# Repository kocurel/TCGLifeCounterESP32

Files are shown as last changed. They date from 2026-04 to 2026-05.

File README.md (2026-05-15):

# An electronic ESP32-C3-powered life counter for Trading Card Games. 
## Made with the players of Magic the Gathering and Yu-Gi-Oh in mind.

The main goal for this project was to implement the basic LifeTap features.
I expanded on some of the features by tracking more variables 
(letting the player rename the value names as they see fit).

Anticipating players making mistakes, the device tracks change history 
letting the player undo to a selected point in time.

As an added extra, I included a dice page that lets the user simulate dice throws using esp_random().
The included dice options are (coin, d3, d4, d6, d8, d10, d12, d20, d100). It's possible to throw 1-4 dice at once and reroll any of the results.

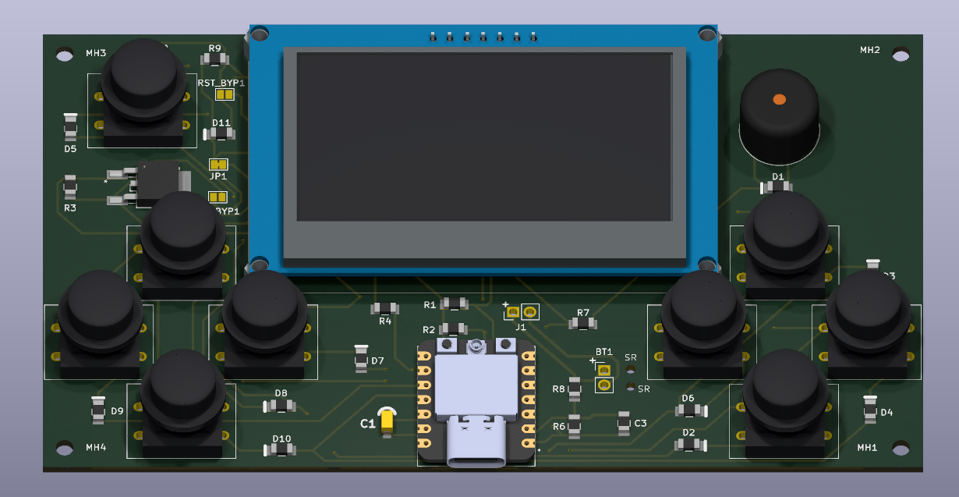
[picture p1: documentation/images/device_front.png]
3D Kicad render

A 3D render generated in Kicad

# The main interface
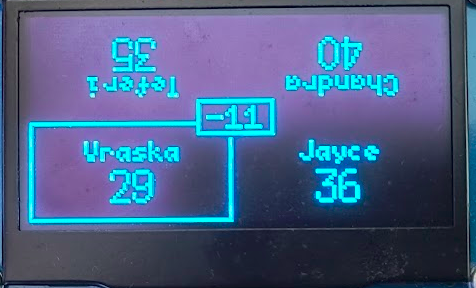
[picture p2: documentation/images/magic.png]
MtG commander gameplay
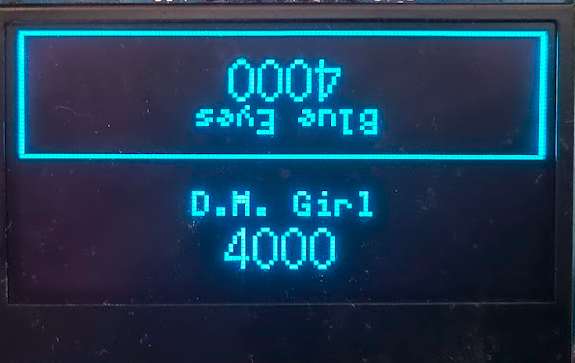
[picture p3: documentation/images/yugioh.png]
Yugioh gameplay
 

# Hardware
The main components of the device are:
1. [SEEED XIAO ESP32-C3](https://botland.store/esp32-wifi-and-bt-modules/21859-seeed-xiao-esp32-c3-wifibluetooth-seeedstudio-113991054.html)
2. [msalamon SSD1309 2.42" OLED display](https://sklep.msalamon.pl/produkt/wyswietlacz-oled-242-128x64px-niebieski/)
3. [A 3x3 12x12mm tactile switch matrix](https://www.tme.eu/pl/en/details/ts24n/microswitches-tact/knitter-switch/ts-24-n/)
4. A passive buzzer
5. 10x 1N4148 diodes
6. A 1050mAh LiPo battery

## The schematics

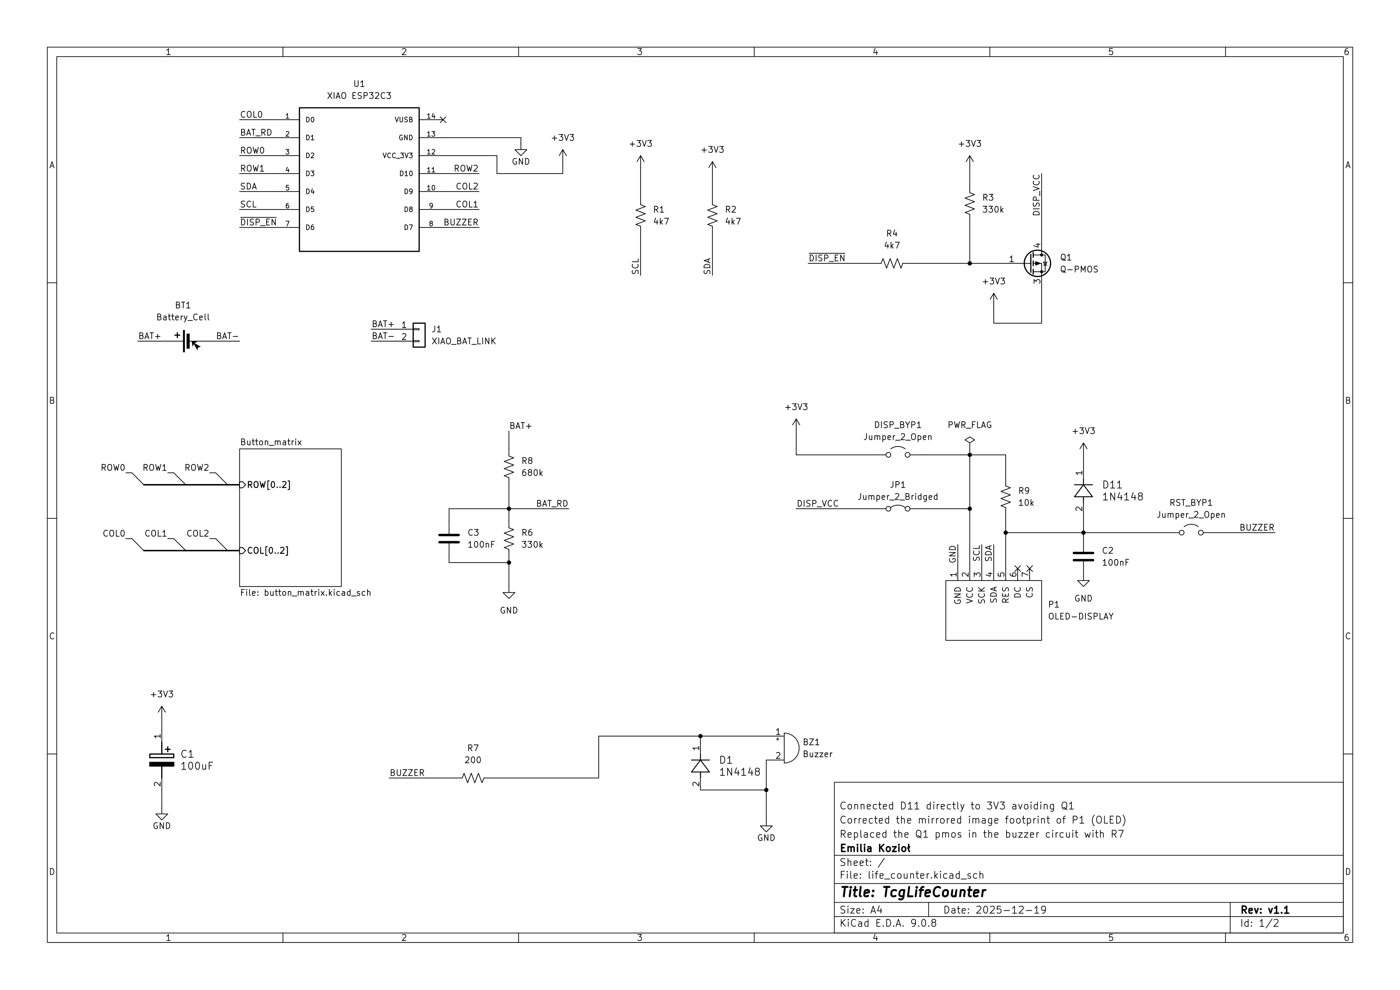
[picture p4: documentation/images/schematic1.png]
Kicad schematic page 1

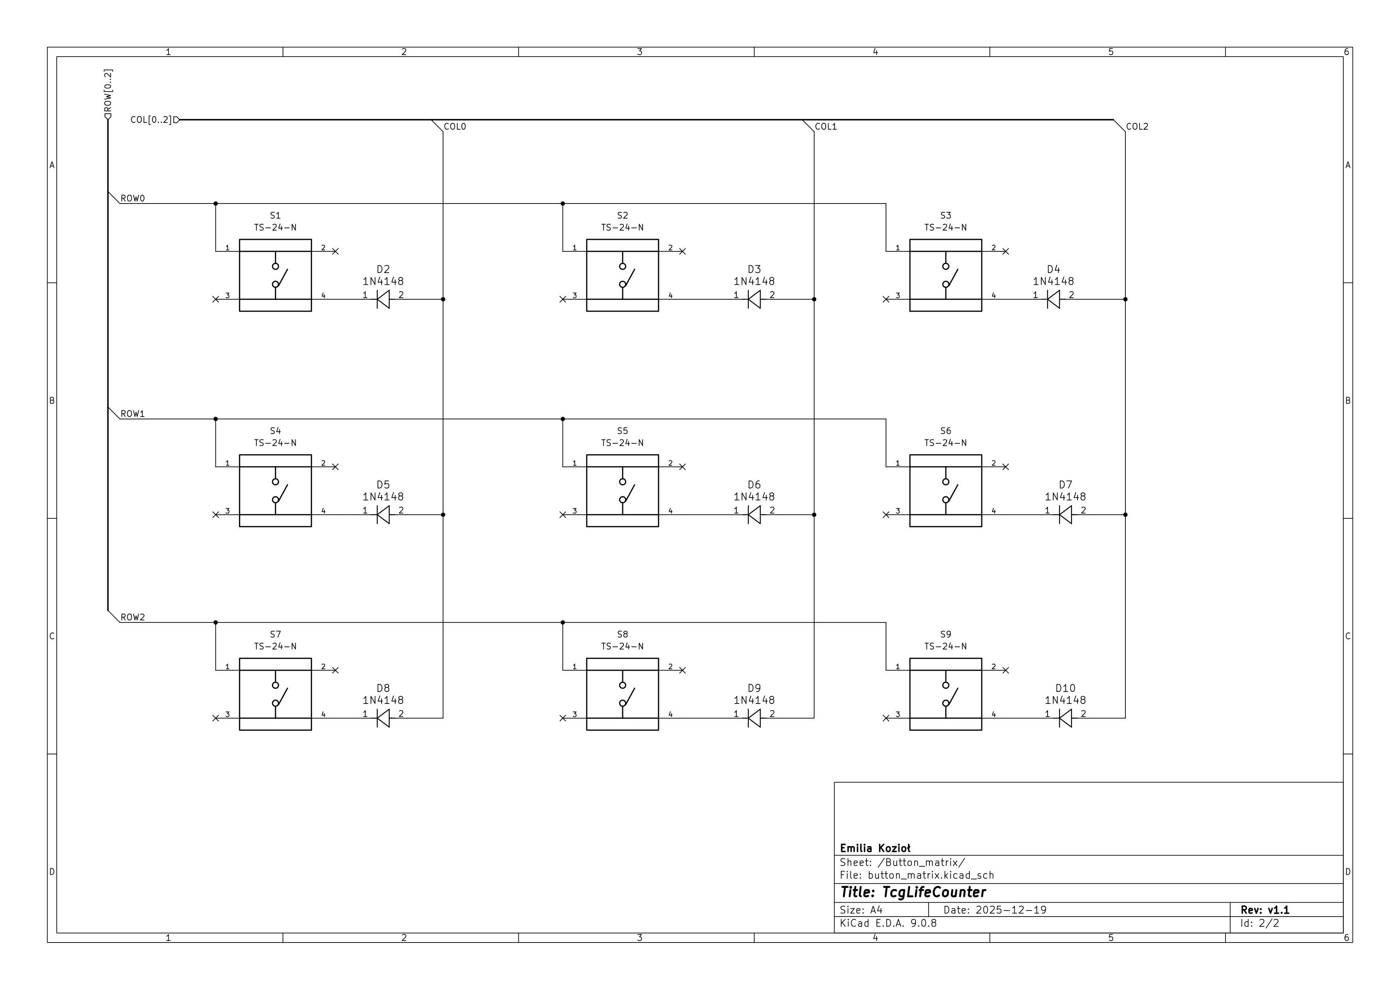
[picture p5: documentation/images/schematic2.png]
Kicad schematic page 2


# Software
When I made the project I used three main components:
1. ESP-IDF
2. [u8g2](https://github.com/olikraus/u8g2)
3. [u8g2-hal-esp-idf](https://github.com/mkfrey/u8g2-hal-esp-idf)

## GUIFramework
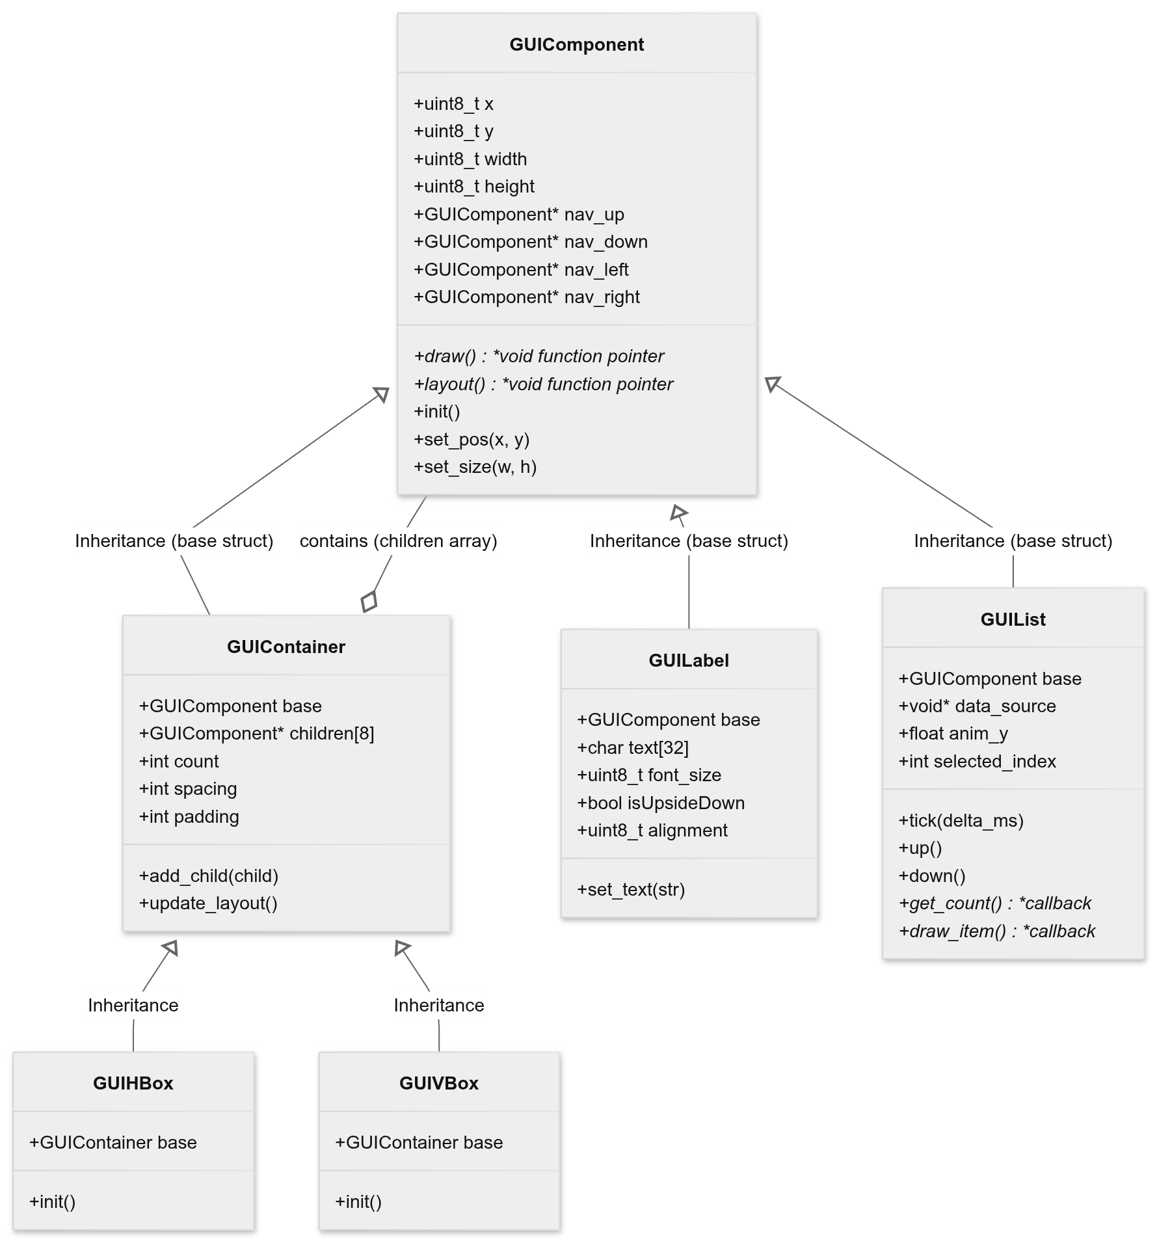
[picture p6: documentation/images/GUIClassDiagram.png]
Class diagram


When designing this device I expected I would need a way to easily design a UI.
I decided to go with a grid-like system using Labels nested in VBoxes and HBoxes.
For an easier time programming I tried to emulate inheritance and OOP in C using vtables.

Later on, I added a GUIList component that uses the delegate design pattern to access the underlying data.

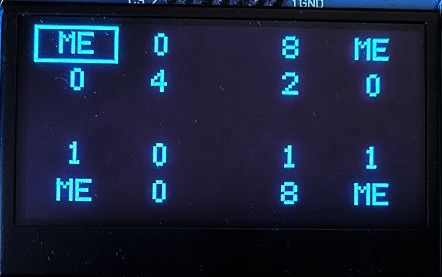
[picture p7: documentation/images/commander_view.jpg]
Commander Page
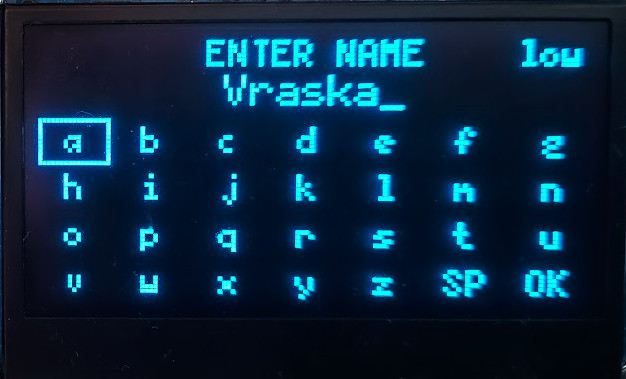
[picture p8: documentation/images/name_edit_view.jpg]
Name Edit Page
 

Using nested containers I was able to get perfectly even grids in my UI without too many manual adjustments.
The navigation pointers inside the GUIComponent made designing the UI navigation really easy.
For extra simplicity I added GUI_LINK_VERTICAL and GUI_LINK_HORIZONTAL macros that automatically assign the pointers.

# About the firmware
## The features
For a better user experience I included a few extra features:
1. Battery level tracking (using ADC and a simple linear interpolation).
2. Automatic, adjustable display timeout to save battery life.
3. Automatic, adjustable power-off (deep sleep) under extended inactivity.
4. Long press of any of the switches reads as multiple presses, going into turbo mode when held for over 1.2s.

## The non-volatile storage
I used NVS to store data between sessions:
1. Device settings
2. Player names
3. Value names

## FreeRTOS
I went with a modular design based on FreeRTOS tasks for easy concurrency handling.
The main tasks include:
1. The main loop that handles rendering and input handling
2. The keypad task that scans the key matrix every 5 ms
3. The battery level read task that reads the battery level every 1 s
4. The audio manager task that uses a non-blocking queue for audio playback

In the development stage I used a command line task to emulate keypad input
that I really don't use anymore but I left it in the code
just in case I have a use for it in the future.

## The buzzer
The buzzer was added so the device has audible feedback on stuff like errors and device waking up.
I control it using the LEDC library of ESP-IDF to play simple tones.

## The key matrix
To save GPIO pins I went with a 3x3 switch matrix. I run a FreeRTOS task that scans the matrix every 5 ms.
For debouncing I use 8 bit unsigned integers as software shift registers. When the last three bits of the register are 1's
the matrix reads a press. Similarly, when the last 3 bits of the register are 0's the matrix reads a release.

## The display
To ensure a smooth user experience, I interface with the SSD1309 OLED display via I2C at 800 kHz. 
This high clock speed allows for fluid animations and a high UI refresh rate.

To minimize standby current draw during inactivity, I implemented a PMOS high-side switch circuit. 
This allows the firmware to completely cut off the VCC rail of the display, effectively extending the battery life.

**In this prototype I have not yet introduced a way to permanently save game state between sessions**

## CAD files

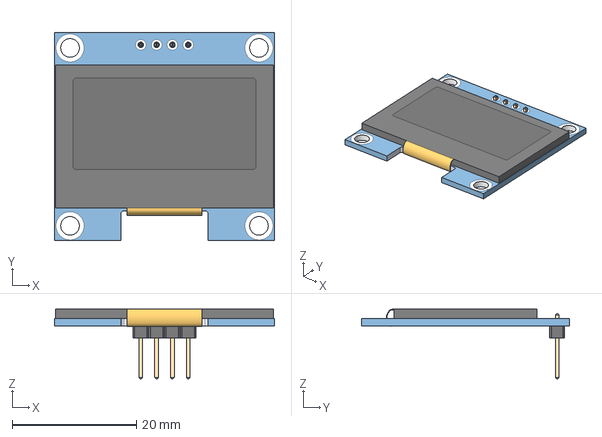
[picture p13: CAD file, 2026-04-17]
Hardware/life_counter/life_counter_libraries/1-3-oled-display-128x64-1.snapshot.5/stp/AZ-Delivery - OLED13 IIC.stp
35.4 x 33.5 x 11.2 mm

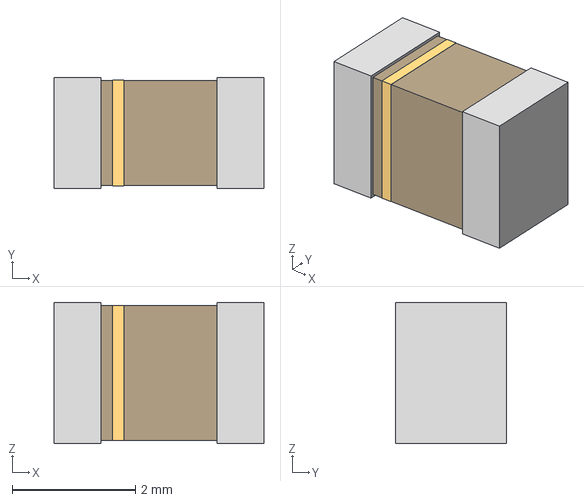
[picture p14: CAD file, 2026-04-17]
Hardware/life_counter/life_counter_libraries/12066D107MAT2A/CAP_1206X_AVX.step
3.40 x 1.80 x 2.29 mm

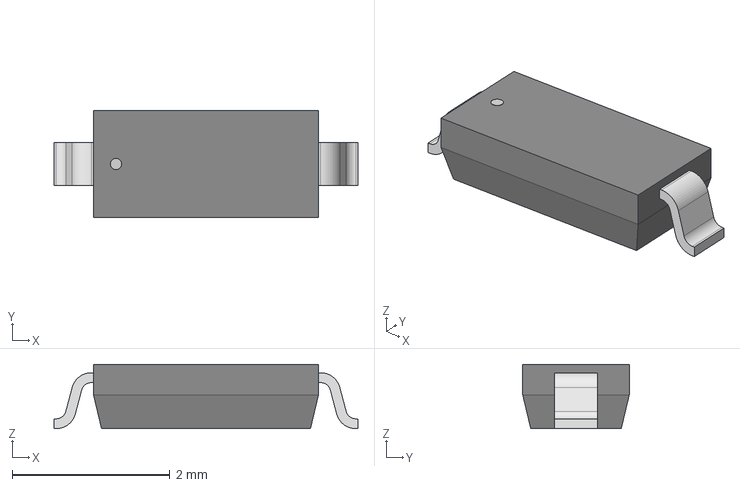
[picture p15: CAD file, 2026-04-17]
Hardware/life_counter/life_counter_libraries/1N4148W_13_F/SOD123_DIO.step
3.85 x 1.35 x 0.815 mm

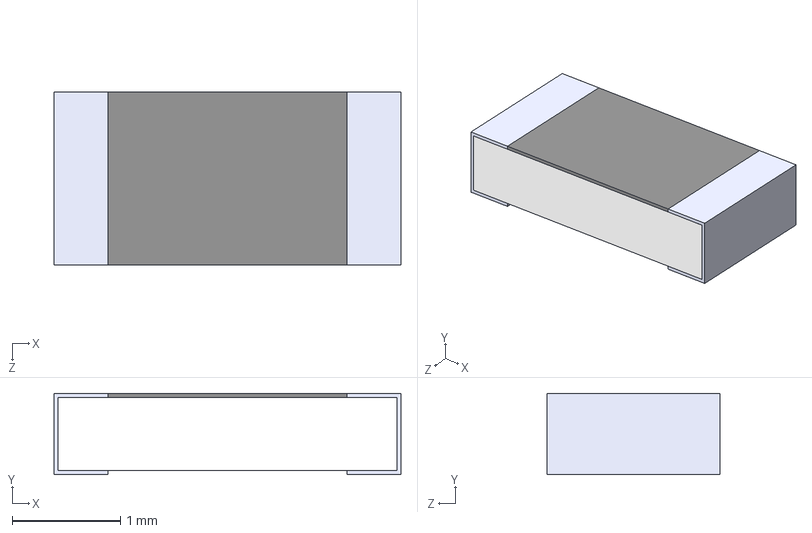
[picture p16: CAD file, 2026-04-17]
Hardware/life_counter/life_counter_libraries/CR1206_JW_334ELF/CR1206-JW-334ELF.step
3.20 x 0.75 x 1.60 mm

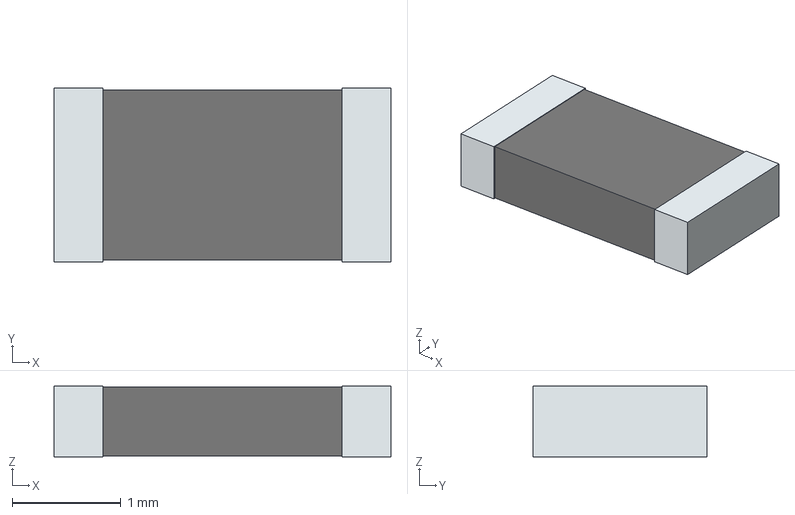
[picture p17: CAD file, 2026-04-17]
Hardware/life_counter/life_counter_libraries/LIB_RC1206FR-074K7L/RC1206FR-074K7L/3D/RC1206FR-074K7L.stp
3.10 x 1.60 x 0.65 mm
term1
term2

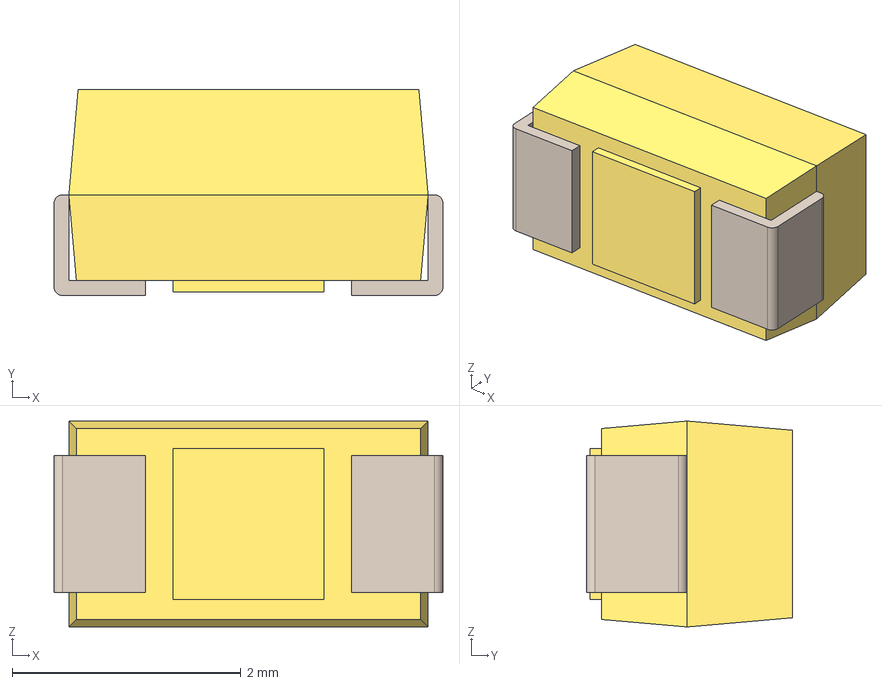
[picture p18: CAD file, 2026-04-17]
Hardware/life_counter/life_counter_libraries/LIB_T520A107M006ATE070/T520A107M006ATE070/3D/T520A107M006ATE070.step
3.40 x 1.80 x 1.80 mm
Case_Bottom_18
Case_Top_18
Case_Cathode_18
Case_Anode_18

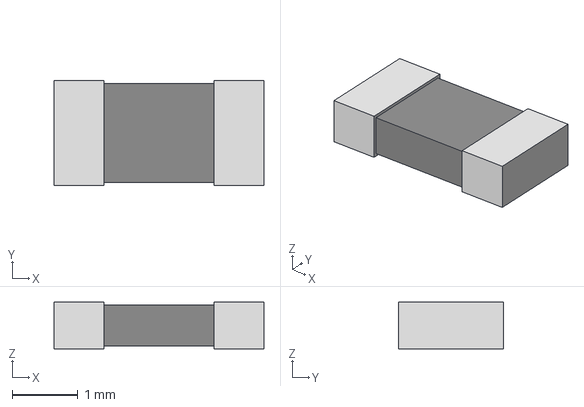
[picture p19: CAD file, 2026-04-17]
Hardware/life_counter/life_counter_libraries/RC1206FR_0710KL/RC1206N_YAG.step
3.20 x 1.60 x 0.711 mm

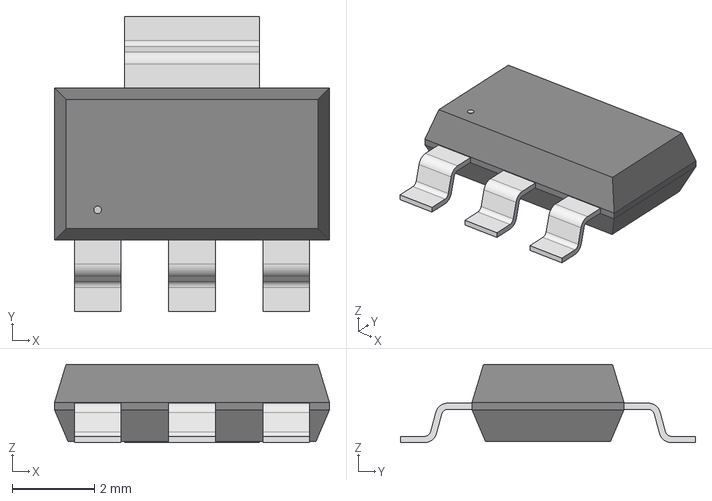
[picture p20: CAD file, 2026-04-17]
Hardware/life_counter/life_counter_libraries/STN3P6F6/SOT223_STN3_STM.step
6.71 x 7.20 x 1.91 mm

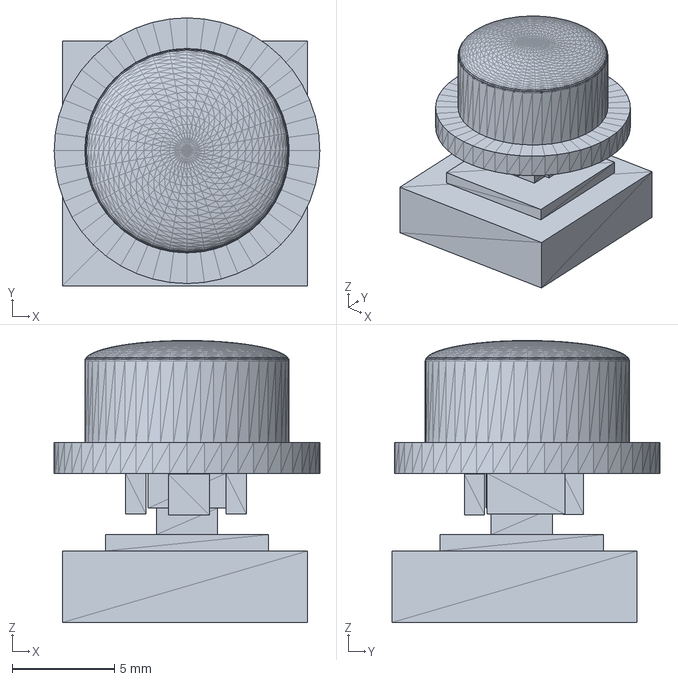
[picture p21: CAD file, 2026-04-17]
Hardware/life_counter/life_counter_libraries/TS-24-N/TS-24-N.step
13.0 x 13.1 x 13.8 mm

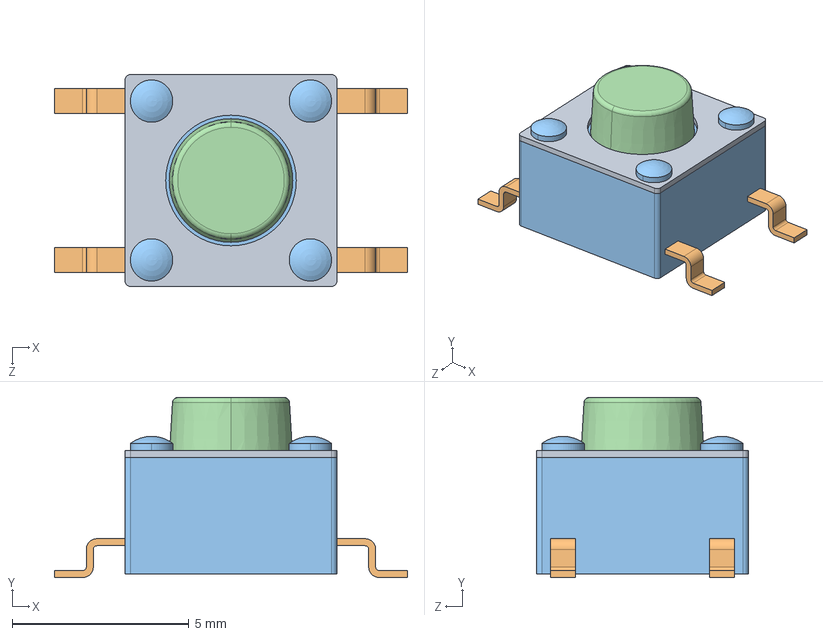
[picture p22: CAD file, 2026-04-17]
Hardware/life_counter/life_counter_libraries/TS04_66_50_BK_160_SMT/TS04-66-50-BK-160-SMT.STEP
10.0 x 5.10 x 6.00 mm

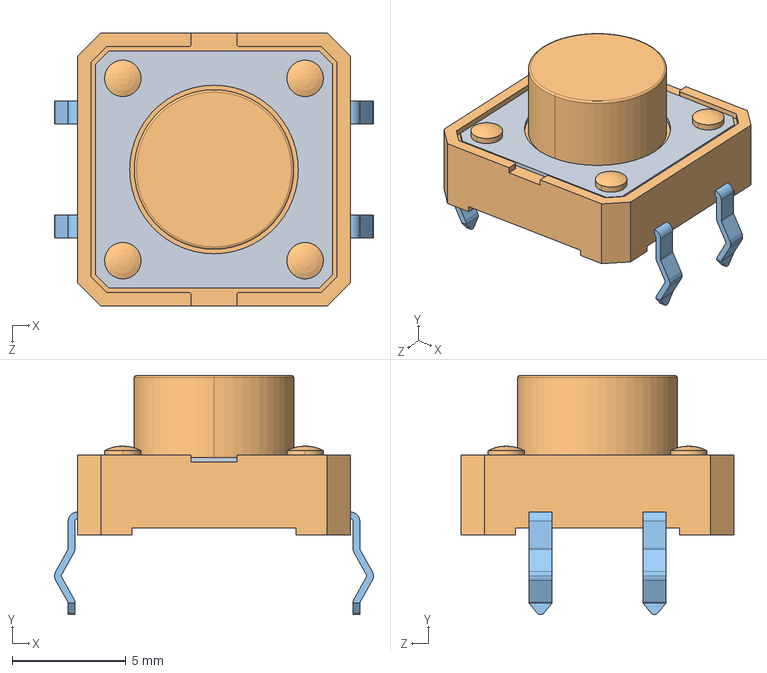
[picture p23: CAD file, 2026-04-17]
Hardware/life_counter/life_counter_libraries/TS14_1212_70_BK_160_SCR_D(1)/TS14-1212-70-BK-160-SCR-D.STEP
14.0 x 10.5 x 12.0 mm

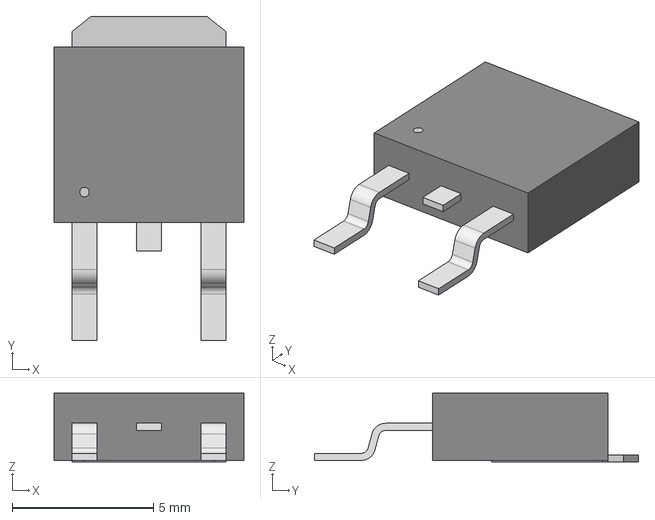
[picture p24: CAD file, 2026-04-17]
Hardware/life_counter/life_counter_libraries/ul_NTD20P06L-001/DPAK-4_6P22X6P73_ONS.step
6.73 x 11.5 x 2.44 mm

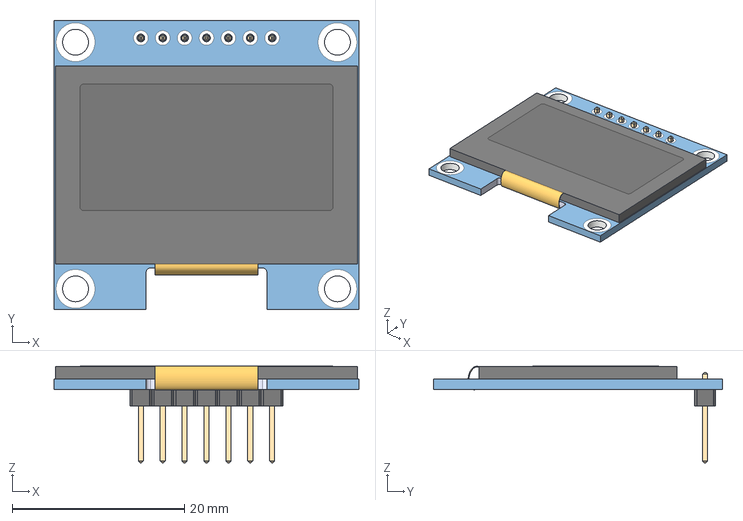
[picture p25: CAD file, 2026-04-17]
Hardware/life_counter/life_counter_libraries/1-3-oled-display-128x64-1.snapshot.5/stp/HiLetgo - DM-OLED13-625.stp
35.4 x 33.5 x 11.2 mm

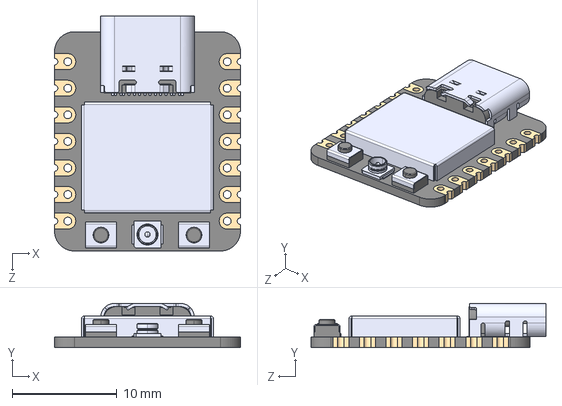
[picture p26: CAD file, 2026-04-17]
Hardware/life_counter/life_counter_libraries/113991054/113991054.step
17.8 x 4.21 x 22.5 mm

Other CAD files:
Hardware/life_counter/life_counter_libraries/RC1206FR_074K7L/RC1206N_YAG.step
Hardware/life_counter/life_counter_libraries/ER-OLEDM013-1-SPI-I2C/ER-OLEDM013-1-SPI-I2C.x_t
Hardware/life_counter/life_counter_libraries/LIB_T520A107M006ATE070/T520A107M006ATE070/3D/T520A107M006ATE070.stp
Hardware/life_counter/life_counter_libraries/LIB_T520A107M006ATE070/T520A107M006ATE070/Allegro/t520a.psm
Hardware/life_counter/life_counter_libraries/LIB_T520A107M006ATE070/T520A107M006ATE070/DEHDL/t520a107m006ate070/chips/chips.prt

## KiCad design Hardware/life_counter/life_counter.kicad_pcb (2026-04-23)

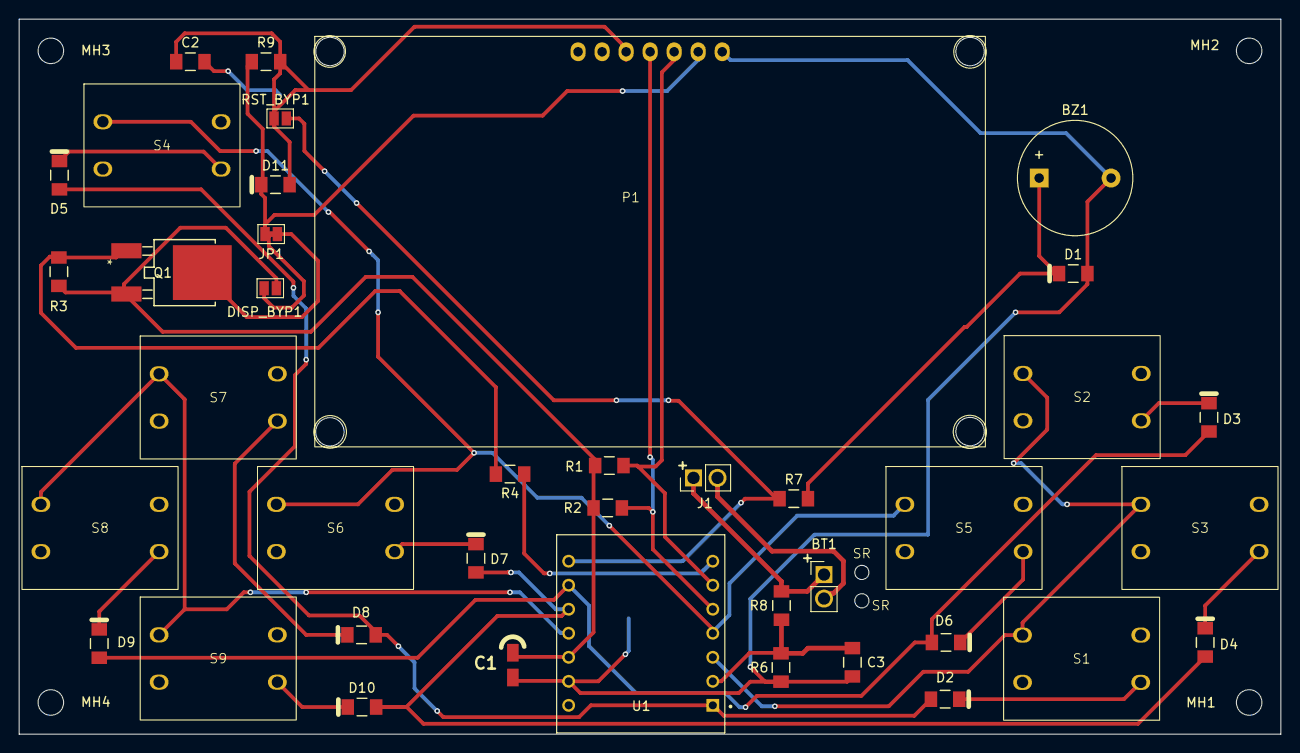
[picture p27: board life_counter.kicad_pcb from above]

Board: 2 copper layers, 133.4 x 75.6 mm, 46 parts (0 on the bottom side), 29 nets.

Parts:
BT1: Battery_Cell; PinHeader_1x02_P2.54mm_Vertical
BZ1: Buzzer; Buzzer_12x9.5RM7.6
C1: 100uF; T520A
C2, C3: 100nF; RC1206N_YAG-M
D1, D2, D3, D4, D5, D6, D7, D8, D9, D10, D11: 1N4148; CD4148W(1206C)
DISP_BYP1: Jumper_2_Open; SolderJumper-2_P1.3mm_Open_Pad1.0x1.5mm
J1: XIAO_BAT_LINK; PinHeader_1x02_P2.54mm_Vertical
JP1: Jumper_2_Bridged; SolderJumper-2_P1.3mm_Bridged_Pad1.0x1.5mm
MH1, MH2, MH3, MH4: MountingHole_2.7mm_M2.5
P1: OLED-DISPLAY; 2.42in128x64OLED
Q1: Q-PMOS; DPAK-4_6P22X6P73_ONS-M
R1, R2, R4: 4k7; RC1206N_YAG-M
R3, R6: 330k; RC1206N_YAG-M
R7: 200; RC1206N_YAG-M
R8: 680k; RC1206N_YAG-M
R9: 10k; RC1206N_YAG-M
RST_BYP1: Jumper_2_Open; SolderJumper-2_P1.3mm_Open_Pad1.0x1.5mm
S1, S2, S3, S4, S5, S6, S7, S8, S9: TS-24-N; TS_24_N_SWITCH
SR: Cable_strain_relief_1.5mm
SR#2: Cable_strain_relief_1.5mm
U1: XIAO ESP32C3; MODULE_113991054

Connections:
+3V3: C1.1 (+), DISP_BYP1.1 (A), Q1.3 (S), R1.1, R2.1, R3.1, U1.12 (VCC_3V3)
/BAT+: BT1.1 (+), J1.1, R8.1
/BAT-: BT1.2 (-), J1.2
/BAT_RD: C3.1, R6.1, R8.2, U1.2 (D1)
/BUZZER: R7.1, RST_BYP1.2 (B), U1.8 (D7)
/Button_matrix/COL0: D2.2, D5.2, D8.2, U1.1 (D0)
/Button_matrix/COL1: D3.2, D6.2, D9.2, U1.9 (D8)
/Button_matrix/COL2: D4.2, D7.2, D10.2, U1.10 (D9)
/Button_matrix/ROW0: S1.1, S2.1, S3.1, U1.3 (D2)
/Button_matrix/ROW1: S4.1, S5.1, S6.1, U1.4 (D3)
/Button_matrix/ROW2: S7.1, S8.1, S9.1, U1.11 (D10)
/DISP_VCC: JP1.1 (A), Q1.4 (D)
/SCL: P1.3 (SCK), R1.2, U1.6 (D5)
/SDA: P1.4 (SDA), R2.2, U1.5 (D4)
/~DISP_EN: R4.1, U1.7 (D6)
GND: BZ1.2 (-), C1.2 (-), C2.2, C3.2, D1.2, P1.1 (GND), R6.2, U1.13 (GND)
unnamed: BZ1.1 (+), D1.1, R7.2
unnamed: D2.1, S1.4
unnamed: D3.1, S2.4
unnamed: D4.1, S3.4
unnamed: D5.1, S4.4
unnamed: D6.1, S5.4
unnamed: D7.1, S6.4
unnamed: D8.1, S7.4
unnamed: D9.1, S8.4
unnamed: D10.1, S9.4
unnamed: D11.1, DISP_BYP1.2 (B), JP1.2 (B), P1.2 (VCC), R9.1
unnamed: C2.1, D11.2, P1.5 (RES), R9.2, RST_BYP1.1 (A)
unnamed: Q1.1 (G), R3.2, R4.2

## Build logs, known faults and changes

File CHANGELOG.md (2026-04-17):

* final (2026-02-06)
* shortened max string length (2026-01-31)
* code cleanup (comments) (2026-01-31)
* value names page, fixed dice page (2026-01-31)
* idfk, zmiana UI main page (2026-01-31)
* added player name change (2026-01-30)
* MVP complete (2026-01-30)
* kill ledc on sleep (2026-01-29)
* update (2026-01-29)
* configured the display, buttons and battery read (2026-01-28)
* configured the project esp to work on linux (2026-01-14)
* moved to linux (2026-01-14)
* history page (2025-12-16)
* added the MenuPage (2025-12-14)
* added the callback to PlayerPage from ValueEditorPage (2025-12-14)
* VALuePageEditor almost ready (2025-12-14)
* ValuePageEditor now displays properly (2025-12-14)
* added ValueEditorPage (2025-12-14)
* fixed centering in CommanderPage (2025-12-14)
* added commander damage page (2025-12-13)
* modified file structure, added PlayerPage (2025-12-13)
* added GUIList (2025-12-13)
* removed memset and added GUI_ADD_CHILDREN() for easier layout management (2025-12-13)
* added navigation function pointers to components for easier menu navigation setup (2025-12-12)
* refactored for static allocation (2025-12-12)
* added more tests (2025-12-11)
* added a few tests (2025-12-11)
* first commit (2025-12-11)

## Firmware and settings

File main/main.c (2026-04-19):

#include <stdio.h>

#include "AudioManager.h"
#include "GUIRenderer.h"
#include "Keypad.h"
#include "PowerManager.h"
#include "app/PageManager.h"
#include "app/pages/ConfirmPage.h"
#include "app/pages/MainPage.h"
#include "battery.h"
#include "console_init.h"
#include "driver/gpio.h"
#include "esp_log.h"
#include "esp_timer.h"
#include "model/Button.h"
#include "model/Game.h"
#include "model/Settings.h"

/**
 * Handles system shutdown sequence upon user confirmation
 */
static void on_power_off_confirmed() {
    ESP_LOGI("app_main", "Power off confirmed. Entering deep sleep.");
    PowerManager_deep_sleep();
}

/**
 * Main application entry point.
 * Manages hardware restoration, task spawning, and the primary event loop.
 */
void app_main(void) {
    /* Restore GPIO states and release pins from Deep Sleep hold mode */
    gpio_reset_pin(5);
    gpio_set_direction(5, GPIO_MODE_OUTPUT);
    gpio_set_level(5, 1);
    gpio_hold_dis(5);
    gpio_deep_sleep_hold_dis();

    /* Restore OLED power rails */
    gpio_reset_pin(21);
    gpio_set_direction(21, GPIO_MODE_OUTPUT);
    gpio_set_level(21, 0);
    gpio_hold_dis(21);

    /* Initialize core subsystems and hardware drivers */
    GUIRenderer_init();
    SettingsModel_init();
    PowerManager_init();
    AudioManager_init();
    keypad_init();

    /* Spawn background service tasks */
    xTaskCreate(console_task, "console_cli", 5120, NULL, 5, NULL);
    xTaskCreate(keypad_scan_task, "keypad_task", 2048, NULL, 5, NULL);
    xTaskCreate(battery_scan_task, "battery_scan_task", 2048, NULL, 5, NULL);

    /* Initialize application state and enter primary UI page */
    Game_init();
    MainPage_enter();
    AudioManager_play_sound(SOUND_GAME_START);

    /* Primary Event Loop: Manages frame timing and input dispatching */
    ButtonCode received_key;
    int64_t last_frame_time = esp_timer_get_time();
    const int64_t frame_duration_us = 20000; /* Target: 50 FPS */

    while (1) {
        int64_t now = esp_timer_get_time();
        const int64_t elapsed = now - last_frame_time;

        /* Process frame logic updates on timing match */
        if (elapsed >= frame_duration_us) {
            PageManager_tick((uint32_t)(elapsed / 1000));
            last_frame_time = now;
        }

        /* Calculate remaining idle time for high-efficiency queue waiting */
        now = esp_timer_get_time();
        const int64_t work_done = now - last_frame_time;
        const int64_t time_to_wait_us = frame_duration_us - work_done;

        TickType_t wait_ticks = 0;
        if (time_to_wait_us > 0) {
            wait_ticks = pdMS_TO_TICKS(time_to_wait_us / 1000);
        }

        /* Input processing with display wake-up logic */
        if (xQueueReceive(get_keypad_queue(), &received_key, wait_ticks)) {
            const bool was_sleeping = PowerManager_is_display_off();
            PowerManager_reset_timer();

            /* Suppress first input event if it was used only to wake the
             * display */
            if (was_sleeping) continue;

            if (received_key == BUTTON_CODE_POWER) {
                ConfirmPage_enter("Power off?", on_power_off_confirmed,
                                  MainPage_enter);
            } else {
                PageManager_handle_input(received_key);
            }
        }
    }
}

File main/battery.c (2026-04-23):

#include "battery.h"

#include "Debug.h"
#include "PowerManager.h"
#include "System.h"
#include "driver/gpio.h"
#include "esp_adc/adc_oneshot.h"
#include "esp_log.h"
#include "freertos/FreeRTOS.h"
#include "freertos/queue.h"
#include "freertos/task.h"

#define BATTERY_ADC_CHANNEL ADC_CHANNEL_3
#define BATTERY_ADC_ATTEN ADC_ATTEN_DB_12
#define NO_OF_SAMPLES 64

typedef struct {
    uint16_t voltage;
    uint8_t percentage;
} battery_level_t;

/* Discharge curve mapping for a standard 3.7V LiPo battery */
static const battery_level_t lipo_table[] = {
    {4200, 100}, {4100, 100}, {4000, 90}, {3800, 60},
    {3700, 40},  {3600, 15},  {3420, 5},  {3300, 0}};

/**
 * Interpolates battery percentage based on calculated battery voltage
 */
int get_battery_percentage(int pin_mv) {
    /* Convert measured pin voltage to actual battery voltage via resistor
     * divider ratio */
    const int battery_mv = (pin_mv * 4200) / 1370;

    if (battery_mv >= 4200) return 100;
    if (battery_mv <= 3000) return 0;

    const int table_size = sizeof(lipo_table) / sizeof(lipo_table[0]);
    for (int i = 0; i < table_size - 1; i++) {
        if (battery_mv >= lipo_table[i + 1].voltage) {
            const int v_high = lipo_table[i].voltage;
            const int v_low = lipo_table[i + 1].voltage;
            const int p_high = lipo_table[i].percentage;
            const int p_low = lipo_table[i + 1].percentage;

            /* Linear interpolation between discharge curve points */
            return p_low +
                   ((battery_mv - v_low) * (p_high - p_low) / (v_high - v_low));
        }
    }

    return 0;
}

/**
 * Executes a hardware ADC read with oversampling for noise reduction
 */
int read_battery_voltage_mv(void) {
    adc_oneshot_unit_handle_t adc1_handle;
    const adc_oneshot_unit_init_cfg_t init_config = {
        .unit_id = ADC_UNIT_1,
        .clk_src = ADC_DIGI_CLK_SRC_DEFAULT,
    };
    ESP_ERROR_CHECK(adc_oneshot_new_unit(&init_config, &adc1_handle));

    const adc_oneshot_chan_cfg_t config = {
        .bitwidth = ADC_BITWIDTH_DEFAULT,
        .atten = BATTERY_ADC_ATTEN,
    };
    ESP_ERROR_CHECK(
        adc_oneshot_config_channel(adc1_handle, BATTERY_ADC_CHANNEL, &config));

    int adc_raw = 0;
    int accumulator = 0;

    for (int i = 0; i < NO_OF_SAMPLES; i++) {
        ESP_ERROR_CHECK(
            adc_oneshot_read(adc1_handle, BATTERY_ADC_CHANNEL, &adc_raw));
        accumulator += adc_raw;
        esp_rom_delay_us(500);
    }

    const int average_raw = accumulator / NO_OF_SAMPLES;
    ESP_ERROR_CHECK(adc_oneshot_del_unit(adc1_handle));

    /* Map 12-bit ADC range to voltage; 2950mV is the approx full-scale at 12dB
     * attenuation */
    const int pin_mv = (average_raw * 2950) / 4095;
    const int bat_mv = (pin_mv * 4200) / 1370;
    const int pct = get_battery_percentage(pin_mv);

    ESP_LOGI("BATTERY", "Pin: %d mV | Bat: %d mV | Level: %d%%", pin_mv, bat_mv,
             pct);

    return pin_mv;
}

void read_battery_level() {
    const int mv = read_battery_voltage_mv();
    const int battery_level = get_battery_percentage(mv);
    // Automatic shut-off at low battery voltage
    if (mv < 3300) {
        ESP_LOGW("PWR", "Battery critical! Entering hibernation.");
        PowerManager_deep_sleep();
    }
    System_set_battery_percentage(battery_level);
    return;
}

/**
 * Background task for periodic battery monitoring
 */
void battery_scan_task(void* pvParameters) {
    while (1) {
        read_battery_level();
        vTaskDelay(pdMS_TO_TICKS(30000));
    }
}

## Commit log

2025-12-13 added commander damage page
    [GUIRenderer.c]
2026-01-28 configured the display, buttons and battery read
2026-01-29 kill ledc on sleep
2026-01-31 value names page, fixed dice page
    [GUIRenderer.c]
2026-01-31 shortened max string length
    [main.c]
2026-04-17 added the hardware kicad project
    [113991054.STEP, 113991054.step, AZ-Delivery - OLED13 IIC.stp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]
2026-04-23 Add README for ESP32-C3 life counter project
2026-04-23 updated the kicad schematics, added auto shut off when battery is at 3.3V, added an image folder forthe github page
    [button_matrix.kicad_sch, life_counter.kicad_pcb, life_counter.kicad_sch]
2026-04-23 Add image to README for device representation
2026-04-23 Add description for 3D render in README
    Added a description for the 3D render in Kicad.
2026-04-23 Rename 'GUI Library' to 'GUIFramework' and expand details
    Updated section title and added description for GUI framework.
2026-04-23 added schematic as pngs
2026-04-23 Add schematics section to README
    Added schematics section with images to README.
2026-04-23 Fix typo in README regarding standby current draw
2026-04-24 Update SEEED XIAO ESP32-C3 link in README
